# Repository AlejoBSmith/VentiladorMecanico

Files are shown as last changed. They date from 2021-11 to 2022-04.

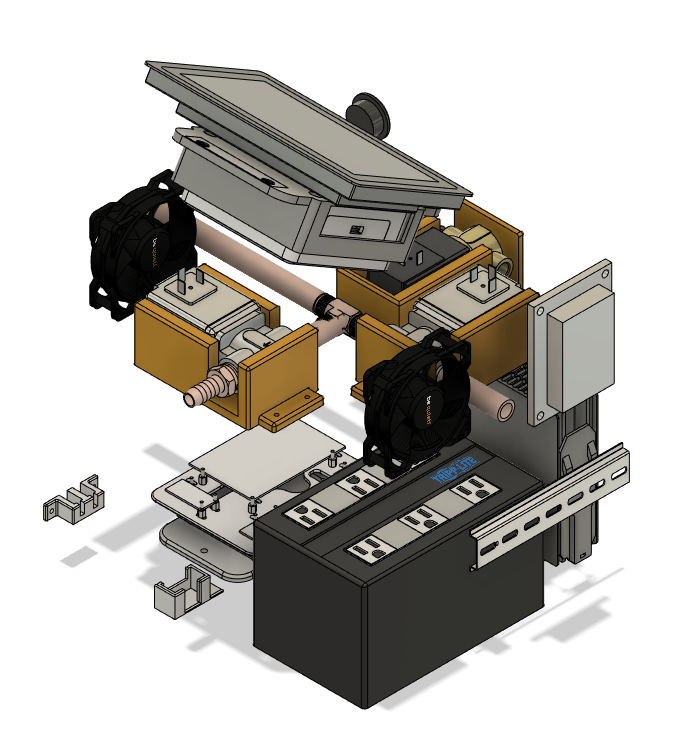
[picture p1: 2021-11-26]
Imágenes/17_materiales.PNG

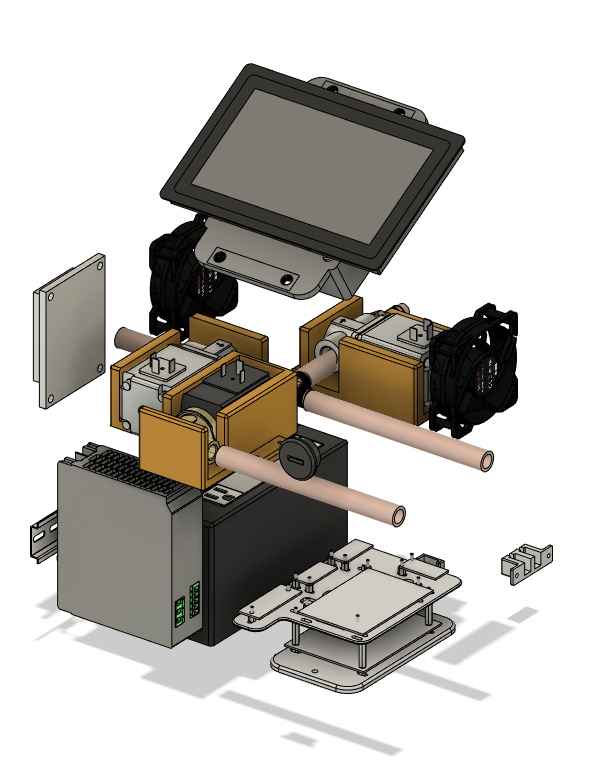
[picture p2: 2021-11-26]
Imágenes/16_materiales.PNG

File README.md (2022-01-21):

# VentiladorMecanico

If used for research purposes, please cite this work as:
A. Von Chong et al., "Low-cost, rapidly deployable emergency mechanical ventilators during the COVID-19 pandemic in a developing country: Comparing development feasibility between bag-valve and positive airway pressure designs," 2021 43rd Annual International Conference of the IEEE Engineering in Medicine & Biology Society (EMBC), 2021, pp. 7629-7635, doi: 10.1109/EMBC46164.2021.9630676.

This repository has been created to share the results of the mechanical ventilator developped in Panama, in response to the COVID-19 pandemic.

The mechanical ventilator is comprised by an electronic system, a pneumatic system, an embedded control algorithm, and a Human-Machine-Interface.

1. Electronic System
The circuit board files are held in folder "Circuito". There are 5 files:
PCB_Pressure_Sensor.json is the pcb for the pressure sensor MPX4006 and its conditioning circuit.
PCB_Main.json is the main circuit where the microcontroller is held and connection point between all sensors and actuators.
PCB_Flyback_diodes.json is an auxiliary circuit for adding the flyback diodes for th electrovalves.
PCB_Electrovalves_Sensors.json is the pcb containing the signals and power cables for the electrovalve's activation and the I2C sensors (flow and differential pressure)
PCB_Schematic is the complete system's electric schematic.

2. Pneumatic System

3. Embedded control algorithm
The system is controlled via a Teensy 4.1 microcontroller. It can be programmed with the Arduino IDE available at https://www.arduino.cc/en/software. The Teensy boards need and additional addon for the Arduino IDE, available at: https://www.pjrc.com/teensy/td_download.html.

Code is available at the "Arduino" folder. "Ventilator_main.ino" is the main code while "Variables.h" is the header file for variable declarations and initialization.

Additional libraries needed are:

4. Human-machine-interface (HMI)
A HMI is needed for data visualization and operating values change. Files for the external case are sized for a Raspberry Pi 10.1 Inch Touchscreen (available at: https://www.amazon.com/gp/product/B095R6SXX1/ref=asin_title?ie=UTF8&th=1). A Windows-based single-board computer (Seeed Studio Odyssey - X86J4125864) for interface hosting via a LabVIEW code available in the "LabVIEW" folder).

External case
The files for acrylic laser cutting of the ventilator's case is in the "Cortadora Láser" folder.

A descriptive video of the whole system is available at: https://youtu.be/rELKO5cxeyU (english) and https://youtu.be/uDOBed04stI (spanish)

Componentes utilizados
Cantidad
Electroválvula de acción directa Burkert        1
Electroválvula proporcional Burkert             2
Microcontroladora Teensy 4.1                    1
Sensor de flujo SFM3000                         1
Sensor diferencial de presión SDP811            1
Sensor de presión MPXV4006                      1
Convertidor analogico – digital ADS 1115        1
Convertidor de Nivel Lógico Bidireccional       1
Fuente DC NDR 120 24                            1
Regulador de Voltaje TrippLite                  1
Pantalla Táctil RPI Touch                       1
Filtro Antibacterial Armstrong                  1
Pulmón Inteligente IMT Analytics Rigel Medical  1
Adaptadores de cobre                            3
Tuberías de cobre                               3
Mosfet 15A 400W XY-MOS                          4
Extensores Micro-USB                            1
Extensores USB                                  2
Cable HDMI                                      1
Cable tipo-C                                    1
Odyssey Mini PC                                 1
Tornillos 6-32mm                                100
Tuercas 6-32mm                                  100
Separadores 30+6mm M.2                          15
Tuercas M.2                                     15
Tornillos 6mm M.2                               15
RielDIN                                         1
Soportes impresos en PLA 3D                     30
Acrílico 6mm espesor /cm2                       9000
Mezclador de Oxígeno                            1

Instructions and a video describing the assembly and operation of the mechanical ventilator will be added soon...

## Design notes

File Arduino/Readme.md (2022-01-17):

To be able to use this code, please download the Arduino dependencies (external libraries), links are provided below:

Sensirion arduino core library available at: https://github.com/Sensirion/arduino-core.git
Adafruit ADS1115 library: https://github.com/adafruit/Adafruit_ADS1X15.git
Adafruit BusIO library: https://github.com/adafruit/Adafruit_BusIO.git
Average.h: https://github.com/kbowerma/arduino/blob/3325685f809cfc3f29808d4946f0ae92c6fa6054/libraries/Average/Average.h
Medianfilterlib2: https://github.com/warhog/Arduino-MedianFilter.git
WTimer: https://github.com/W-walter70/WTimer-1.0-for-Arduino
StringSplitter: https://github.com/aharshac/StringSplitter.git

Modifications:
StringSplitter.h must be changed in line 14 to (at least) MAX=15

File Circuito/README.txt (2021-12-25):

Documents for Mechanical Ventilator's PCB crafting

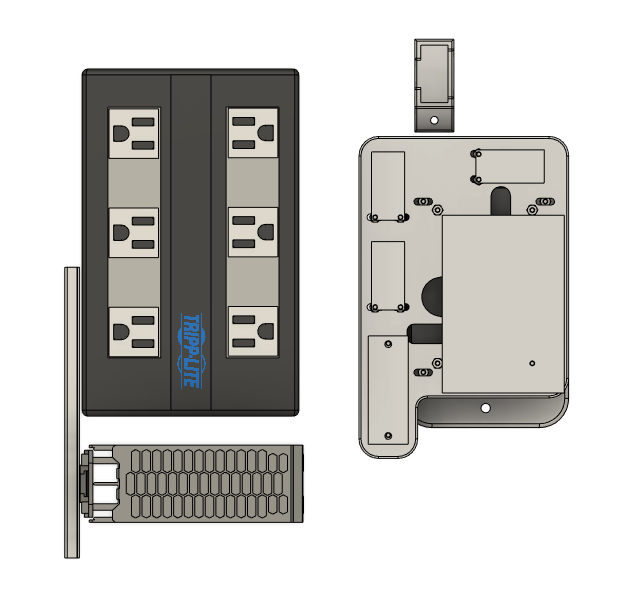
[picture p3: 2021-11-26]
Imágenes/19_electronica.PNG

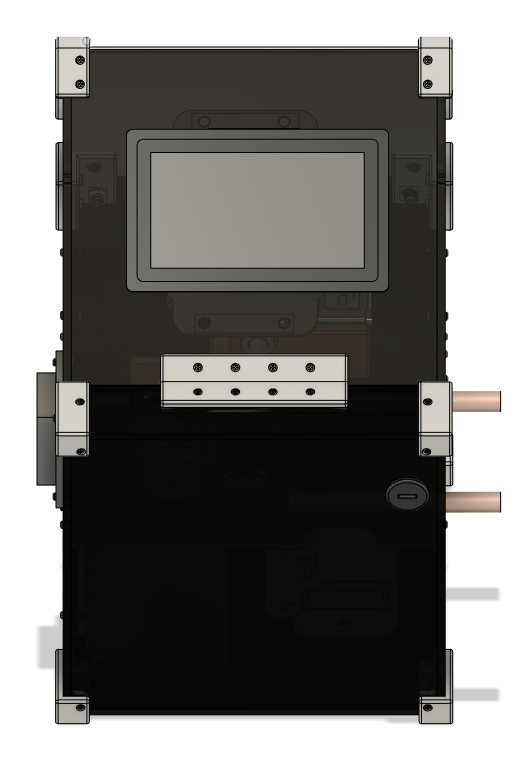
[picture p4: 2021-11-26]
Imágenes/3_isometrico.PNG

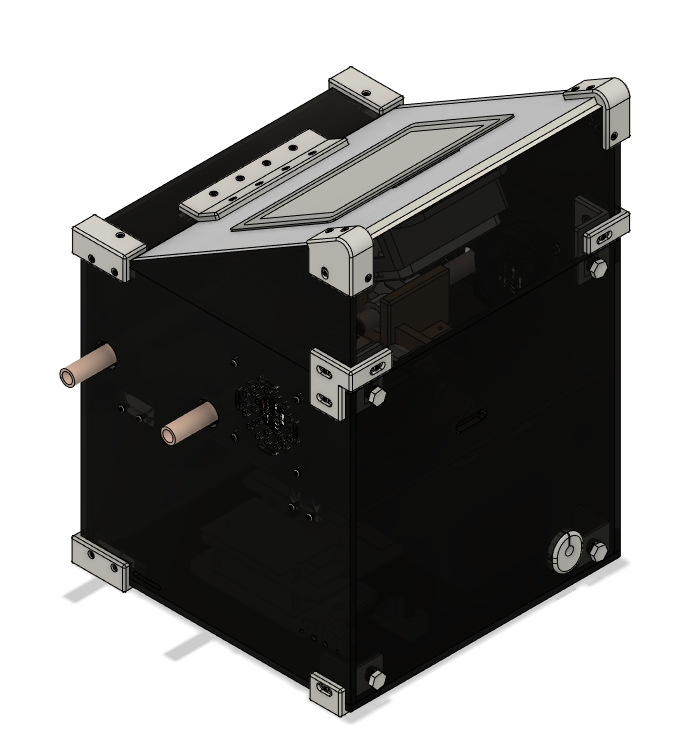
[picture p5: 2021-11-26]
Imágenes/6_isometrico.PNG

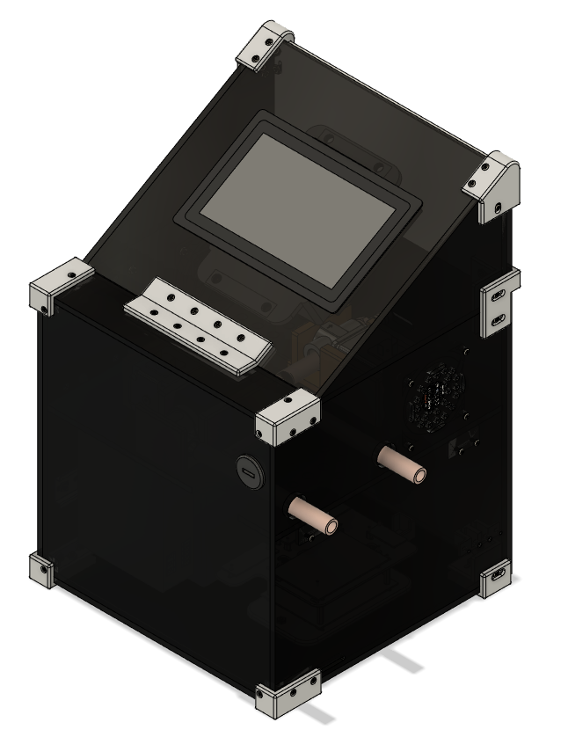
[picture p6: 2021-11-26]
Imágenes/2_isometrico.PNG

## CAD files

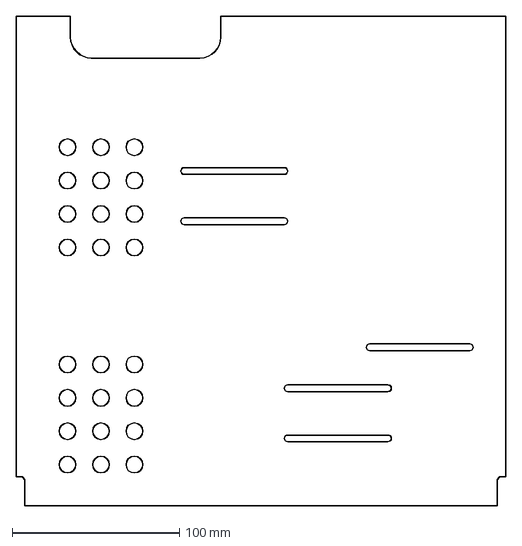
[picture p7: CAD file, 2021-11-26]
Cortadora Láser/Nivel1.dxf
293.0 x 293.0 mm

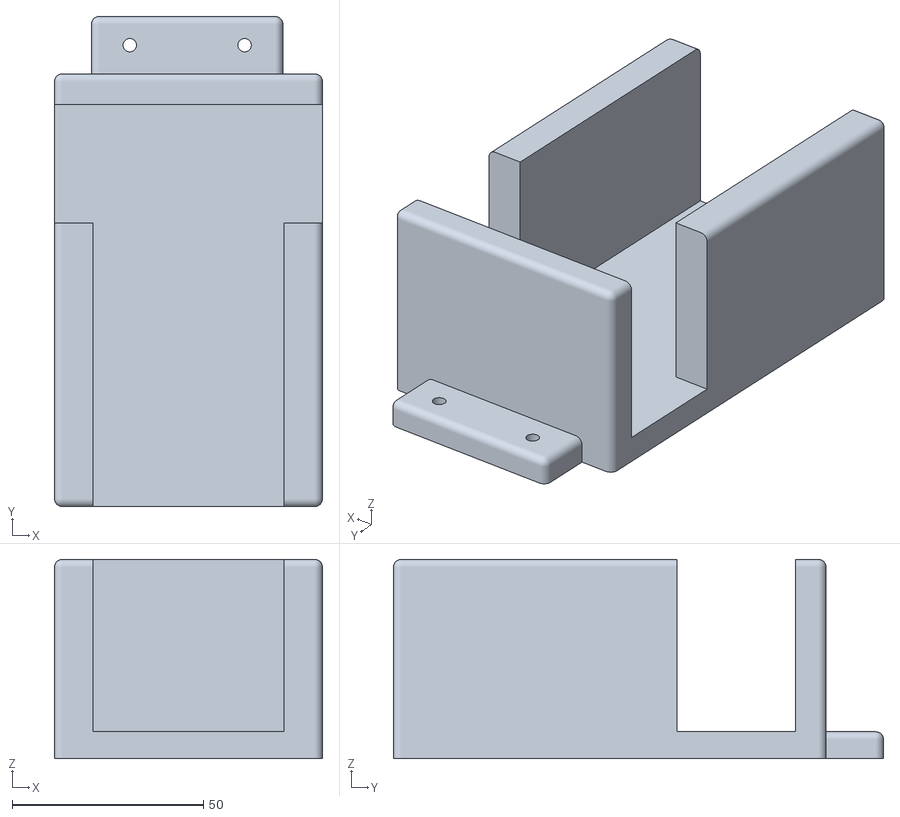
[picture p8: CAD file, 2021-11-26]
Impresión 3D/1_Electrovalvulas/Soporte2875.stl
70.0 x 128.0 x 52.0

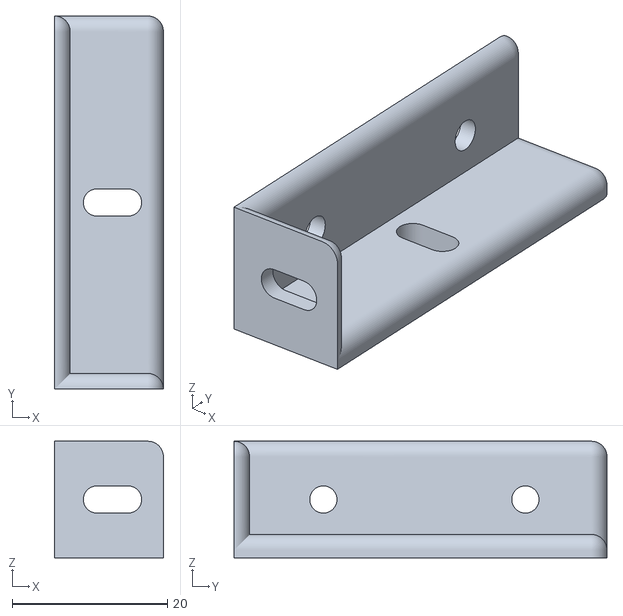
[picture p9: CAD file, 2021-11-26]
Impresión 3D/2_Inferiores/Izq_Inf_Int.stl
14.0 x 48.0 x 15.0

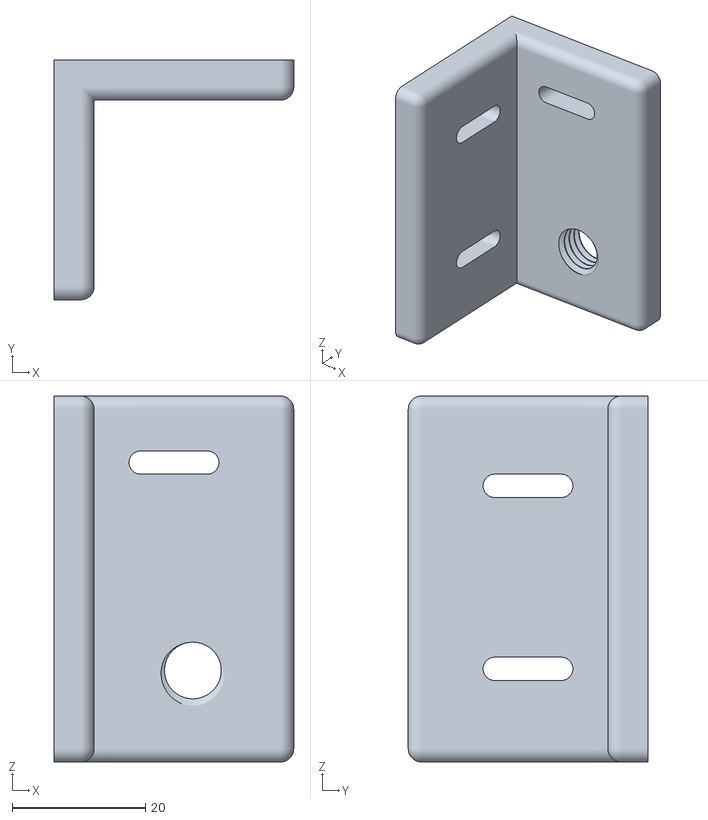
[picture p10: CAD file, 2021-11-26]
Impresión 3D/3_Superiores/Tra_Izq_Int_Sup_R.stl
36.0 x 36.0 x 55.0

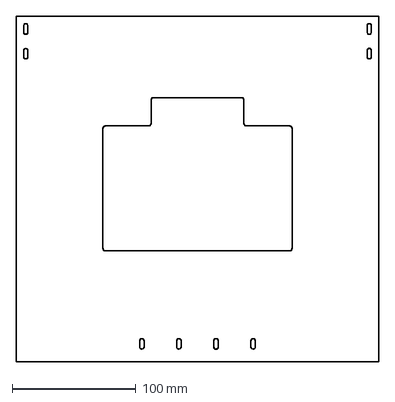
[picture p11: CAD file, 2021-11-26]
Cortadora Láser/paredFrontalInc.dxf
293.0 x 279.3 mm

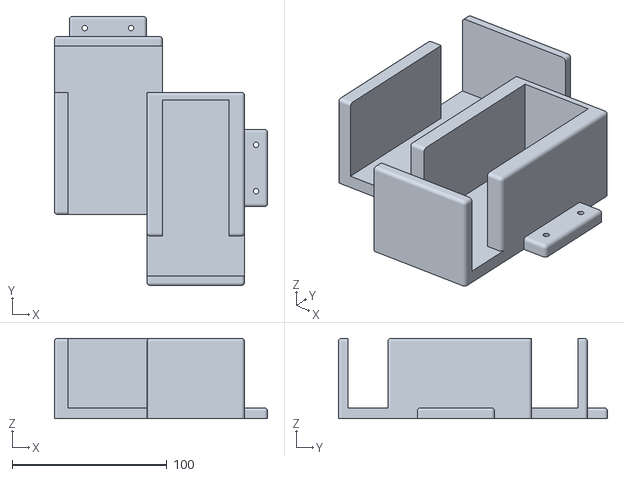
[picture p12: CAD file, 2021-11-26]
Impresión 3D/1_Electrovalvulas/Soporte2875-6027.stl
138.0 x 174.0 x 52.0

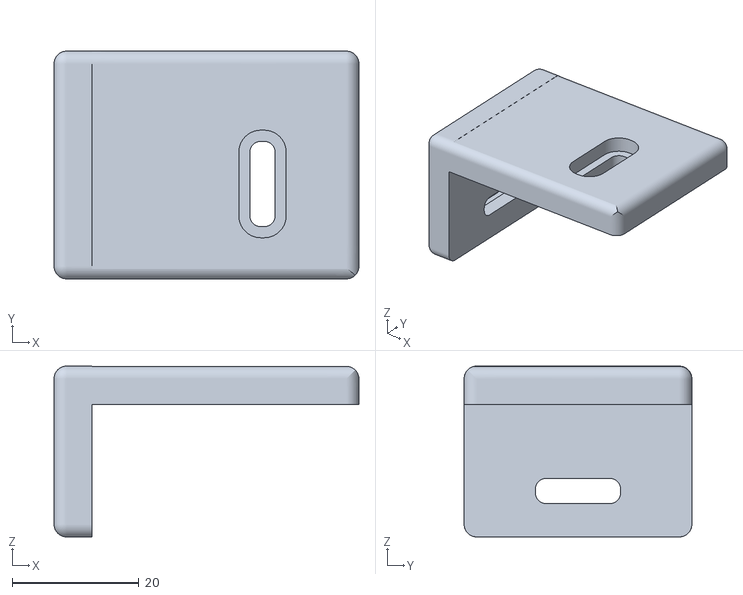
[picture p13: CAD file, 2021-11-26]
Impresión 3D/2_Inferiores/Tra_Der_Ext_Inf_R.stl
48.2 x 36.0 x 27.0

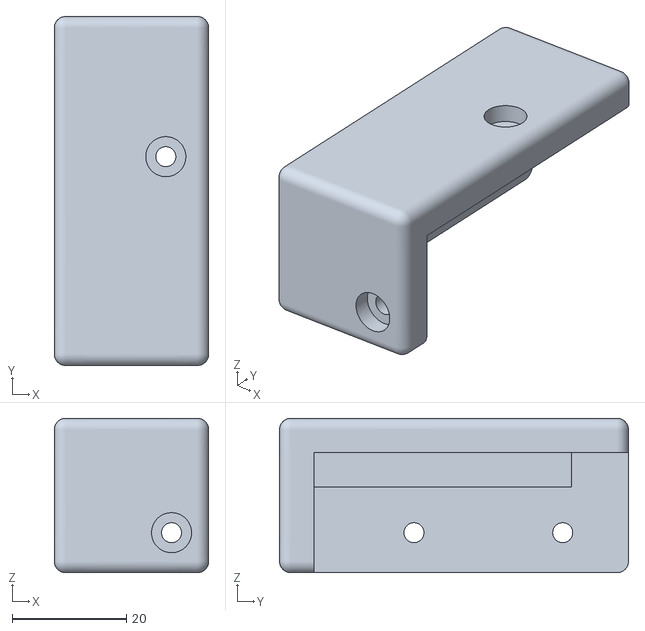
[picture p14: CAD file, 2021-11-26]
Impresión 3D/3_Superiores/Sup_Izq.stl
27.0 x 61.0 x 27.0

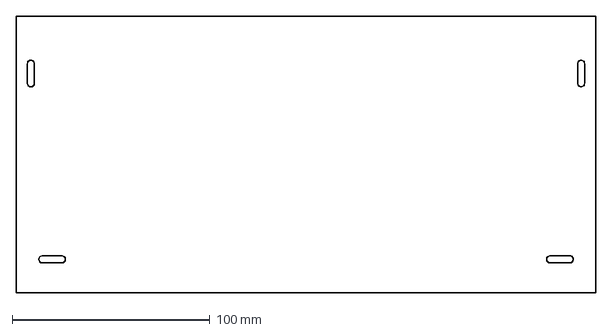
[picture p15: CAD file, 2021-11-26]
Cortadora Láser/paredTraseroSup.dxf
293.0 x 139.9 mm

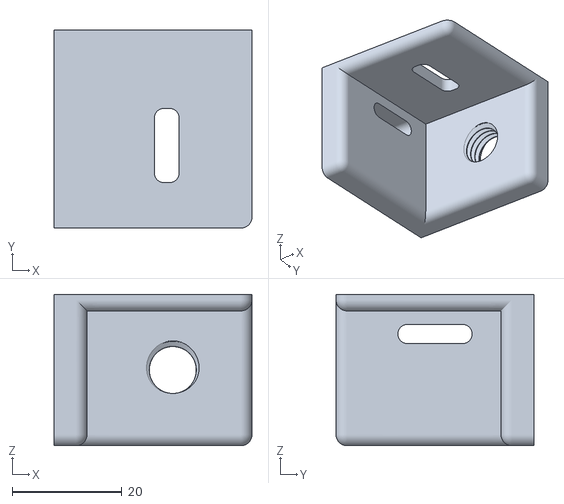
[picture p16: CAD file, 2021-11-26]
Impresión 3D/2_Inferiores/Tra_Der_Int_Inf_R.stl
36.0 x 36.0 x 27.5

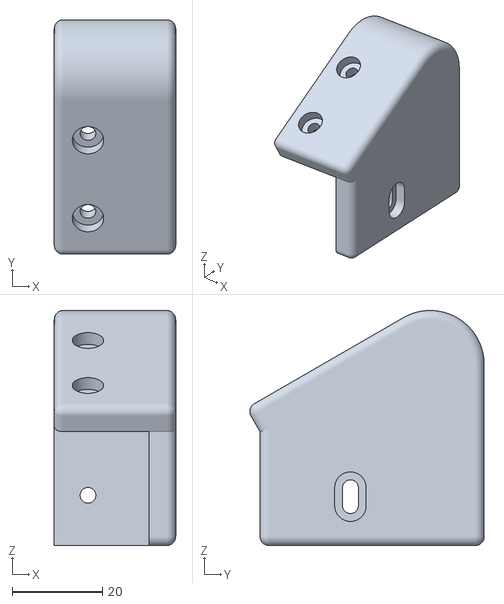
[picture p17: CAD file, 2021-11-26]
Impresión 3D/3_Superiores/Esq_Der_Sup.stl
27.0 x 52.1 x 52.2

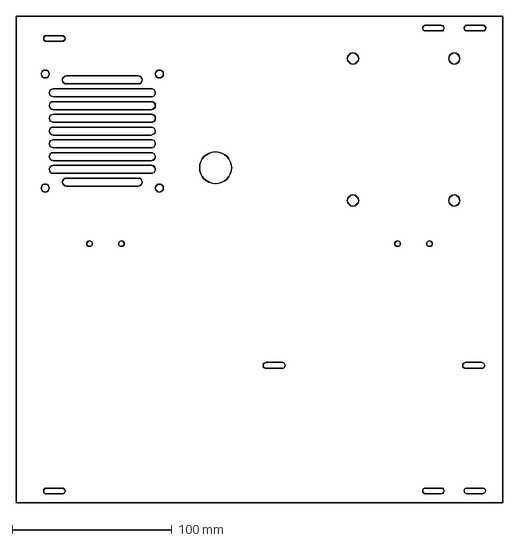
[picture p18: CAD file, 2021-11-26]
Cortadora Láser/paredIzquierdoInf.dxf
305.0 x 305.0 mm

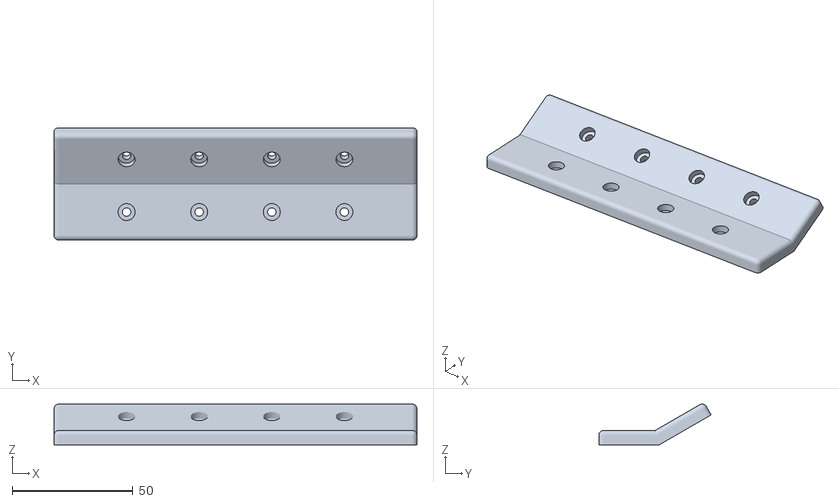
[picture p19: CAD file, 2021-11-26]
Impresión 3D/3_Superiores/Inclinado.stl
150.0 x 46.5 x 16.9

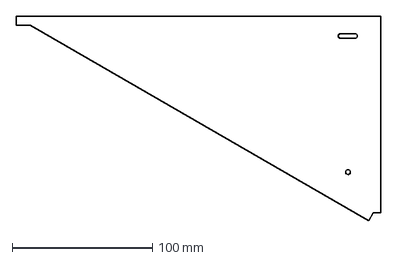
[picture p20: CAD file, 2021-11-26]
Cortadora Láser/paredIzquierdoSup.dxf
259.5 x 145.6 mm

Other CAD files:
Impresión 3D/2_Inferiores/Der_Inf_Ext.stl
Impresión 3D/2_Inferiores/Nivel1.stl
Impresión 3D/3_Superiores/Tra_Izq_Ext_Sup_R.stl
Cortadora Láser/paredFrontal.dxf
Cortadora Láser/Nivel0.dxf
Cortadora Láser/paredDerechoSup.dxf
Impresión 3D/2_Inferiores/Der_Inf_Int.stl
Impresión 3D/2_Inferiores/Izq_Inf_Ext.stl
Impresión 3D/2_Inferiores/Tra_Izq_Ext_Inf_R.stl
Impresión 3D/2_Inferiores/Tra_Izq_Int_Inf_R.stl
Impresión 3D/3_Superiores/Esq_Izq_Sup.stl
Impresión 3D/3_Superiores/Inclinado_Int.stl
Impresión 3D/3_Superiores/Sup_Der.stl
Impresión 3D/3_Superiores/Sup_Der_Int.stl
Impresión 3D/3_Superiores/Sup_Izq_Int.stl
Impresión 3D/3_Superiores/Tra_Der_Ext_Sup_R.stl
Impresión 3D/3_Superiores/Tra_Der_Inr_Sup_R.stl

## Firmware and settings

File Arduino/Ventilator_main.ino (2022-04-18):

// Corregir rutina de sdp811, actualmente dura 10 ms

#include <StringSplitter.h>
#include <WTimer.h>
#include <Wire.h>
#include <Adafruit_ADS1X15.h>
#include <MedianFilterLib2.h>
#include <movingAvg.h>
#include <Average.h>
#include <Separador.h>
#include "Variables.h"
#include <Arduino.h>
#include <SensirionI2CSdp.h>
#define sfm3300i2c 0x40

MedianFilter2<int> medianFilter2(3);
WTimer mytimers;
Adafruit_ADS1115 ads1115;
Separador HMI;
SensirionI2CSdp sdp;
elapsedMillis PlatTimer;
elapsedMillis ExhTimer;
elapsedMillis PCTimer;
elapsedMillis VCTimerInsp;

//Averaging functions:
movingAvg VIF_promedio(5);
movingAvg VEF_promedio(5);
movingAvg PIP_promedio(5);
movingAvg promediomovil(2);

void setup()
{
  //Set Teensys' IO pins and PWM frequency (PWM frequency is given in valve's datasheets)
  pinMode(Val_Ins,OUTPUT);
  pinMode(Val_Exh,OUTPUT);
  analogWriteFrequency(36,Frecuencia);
  analogWriteResolution(Resolucion);

  //Start averaging functions
  promediomovil.begin();
  VIF_promedio.begin();
  VEF_promedio.begin();
  PIP_promedio.begin();
 
  //--------------------------------------------------------------
  // Starts ADS1115 ADC
  ads1115.begin(0x48); //Address is 0x48 when ADDR pin is connected to GND
  ads1115.setDataRate(RATE_ADS1115_860SPS);
  // Starts communication with Sensirion SFM3300
  Wire.begin(); // Iniciar comunicación I2C
  while(!Serial) {} // let serial console settle
  Wire.beginTransmission(sfm3300i2c);
  Wire.write(0x10);
  Wire.write(0x00);
  Wire.endTransmission();
  //Starts communication with Sensirion SDP811
  sdp.begin(Wire, SDP8XX_I2C_ADDRESS_1);
  sdp.stopContinuousMeasurement();
  error_sdp = sdp.readProductIdentifier(productNumber, serialNumber, serialNumberSize);
  error_sdp = sdp.startContinuousMeasurementWithDiffPressureTCompAndAveraging();
  //--------------------------------------------------------------
}

void loop()
{
// First check if any of the operating values from the HMI have changed
  if (Serial.available() > 0)
  {
    StringEntrada = Serial.readStringUntil('\n');
    StringSplitter *splitter = new StringSplitter(StringEntrada, ',', 40);  // new StringSplitter(string_to_split, delimiter, limit)
    inicio = splitter->getItemAtIndex(0).toInt();
    Porcentaje_apertura_valvula = splitter->getItemAtIndex(1).toInt();
    presion_soporte = splitter->getItemAtIndex(2).toInt();
    Peep_deseado = splitter->getItemAtIndex(3).toInt();
    Volumen_deseado = splitter->getItemAtIndex(4).toInt();
    Tiempo_Expiracion_ms = splitter->getItemAtIndex(5).toInt();
    Tiempo_Plateau_ms = splitter->getItemAtIndex(6).toInt();
    inicio_modoAsistido=splitter->getItemAtIndex(7).toInt();
    Start_caract=splitter->getItemAtIndex(8).toInt();
    TipoCaract_Rampa=splitter->getItemAtIndex(9).toInt();
    TipoCaract_Escalon=splitter->getItemAtIndex(10).toInt();
    Tiempo_InspiracionPC_ms=splitter->getItemAtIndex(11).toInt();
    kp=splitter->getItemAtIndex(12).toInt();
    ki=splitter->getItemAtIndex(13).toInt();
    ModoOperacion=splitter->getItemAtIndex(14).toInt();
  }
 
  mytimers.runTimers(millis()); //Timing function

  //------------------------------------------------------------------------------
  // Read sensors
  LeerADS1115();
  LeerSFM3300();
  LeerSDP811();
  //------------------------------------------------------------------------------

  Calculos(); //Sensor data conversion
  Mostrar_Datos(); //Sends variables through serial port
  modoAsistido(Presion);
 
  //Cycle time
  tiempofinal_ciclo=tiempoinicial_ciclo;
  tiempoinicial_ciclo=millis();
  deltaT_ciclo=tiempoinicial_ciclo-tiempofinal_ciclo;

  if (deltaT_ciclo <= 50)
  {
  acc_ciclo=acc_ciclo+deltaT_ciclo;
  }
 
  switch (estado)
  {
    //-------------------------------------------------------
    case 0: // Idle
      caso = 0;
      CierreValvulaInspiracion(); //Keeps inspiratory valve closed
      AperturaValvulaExhalacion(); //Keeps expiratory valve open
      volumen_inspiracion = 0;
      EtapaResp = 0;
      acc_ciclo = 0;
      VIF = 0;
      PIP = 0;
     
      if (inicio == 1 && Start_caract == 0 && Zero_calibration == 0) // Begins respiratory cycle and forces other operating modes to false
      {
        Start_caract = false;
        Zero_calibration = false;
        offsetFlow = sensor_flujo_bits;
        offsetPressure = ((0.002131)*sensor_presion_bits) -3.565;
        offsetDiffPress = sensor_diferencial_bits/37960.3;
        estado = 1;
      }
      if(Start_caract== 1 && inicio == 0 && Zero_calibration == 0) // Begins system characterization and forces other operating modes to false
      {
        n = valor_inicial_PWM;
        estado = 10;
      }
      if (Zero_calibration == 1 && inicio == 0 && Start_caract == 0) // Sets offset values for sensor readings
      {
        f = 1;
        estado = 11;  
      }      
    break;
  //-------------------------------------------------------        
    case 1:
      AuxEtapa = false;
      caso = 1;
      if (Caract_Pulmon == 1) //Varies PWM output only if lung characterization is chosen
      {
        if(AuxCaractPulmon >= valor_final_PWM)
        {
          AuxCaractPulmon = valor_inicial_PWM;
          inicio = 0;
        }
        else
        {
        AuxCaractPulmon = AuxCaractPulmon + 50;
        }
      }
      tiempo_ciclo_actual= millis();
      PCTimer = 0; //only for first breath
      VCTimerInsp = 0;
      estado = 2;
      volumen_inspiracion=0; //Reset inspiratory volume to avoid integral drift
    break;
  //-------------------------------------------------------
    case 2: //Inspiration begin    
      EtapaResp = 1;
      caso = 2;
      CierreValvulaExhalacion();
      volumen_inspiracion += Flujo*deltaT_ciclo/60;

      if (ModoOperacion == 1) // Volume control mode
      {
        if(Presion >= (Peep_deseado + presion_soporte)||(Volumen_deseado <=  volumen_inspiracion)||(VCTimerInsp>Tiempo_max_insp_VC))
        {            
          // Closes inspiration valve if pressure or volume are exceeded
          CierreValvulaInspiracion();
          PIP = Presion;
          PlatTimer = 0;
          estado = 3; //State change
        }
        else // Opens inspiratory valve if neither set pressure or volume have been reached
        {
          EstadoValvulaInspiracion = true;
          if(Caract_Pulmon == 1) //For lung characterization, variable pwm
          {
            analogWrite(Val_Ins,AuxCaractPulmon);
          }
          else
          {
            AperturaValvulaInspiracion();
          }
        }
      }
      if (ModoOperacion == 0) //Pressure control mode
      {
        if ((PCTimer >= Tiempo_InspiracionPC_ms)||(Volumen_deseado <=  volumen_inspiracion))
        {
          // Maintains desired pressure until preset time is reached or volume is exceeded
          CierreValvulaInspiracion();
          PIP = Presion;
          errorIntegral = 0;
          PlatTimer = 0;
          estado = 3; //State change
        }
        else
        {
          EstadoValvulaInspiracion = true;
          AperturaValvulaInspiracion();
        }
      }
    break;
  //-------------------------------------------------------
    case 3: //Plateau (hold) time
      caso = 3;
      EtapaResp = 2;
      if (ModoOperacion == 1)
      {
        if ((PlatTimer >= Tiempo_Plateau_ms))
        {
          Pplat = Presion;
          ExhTimer = 0;
          Tiempo_Inspiracion = (millis()- tiempo_ciclo_actual)/1000; // Inspiration time including hold calc
          estado = 4;
          AperturaValvulaExhalacion();          
        }
      }
      else
      {
        Pplat = Presion;
        ExhTimer = 0;
        Tiempo_Inspiracion = (millis()- tiempo_ciclo_actual)/1000; // Inspiration time including hold calc
        estado = 4;
        AperturaValvulaExhalacion();
      }
    break;
  //-------------------------------------------------------
    case 4: //Exhalacion    
      caso = 4;
      if (ExhTimer >= Tiempo_Expiracion_ms)
      {
        Peep = Presion;
        if (inicio==1)
        {
          PCTimer = 0;
          VCTimerInsp = 0;
          estado = 2;
          volumen_inspiracion = 0;
          PwmOutAux = valor_inicial_PWM;
        }
        else
        {
          estado=0;
        }
        EtapaResp =3 ;  
        duracion_ciclo=acc_ciclo; //en ms  
        acc_ciclo=0; //reinicia el contador del tiempo para los BPM
      }
      else
      {
        if (inicio_modoAsistido ==1) //If assisted mode is on
        {
          if (ExhTimer >= (Tiempo_Expiracion_ms/3)) //Checks wether 33% of expiratory time has passed before checking pressure variability threshold
          {
            if (abs(derivada)>=10) //Pressure sensitivity (diff Pressure)
            {
              PCTimer = 0;
              estado = 1; //Starts a new inpiratory cycle
              duracion_ciclo=acc_ciclo;
              acc_ciclo=0;
              ExhTimer=0;
              break;
            }
          }
        }
        if(Presion <= Peep_deseado)   //PEEP setting
        {
          EtapaResp = 4;
          AuxEtapa = true;
          CierreValvulaExhalacion();      
        }
        else
        {
          if(AuxEtapa == false)
          EtapaResp = 5;          
        }
      }
    break;
  //-------------------------------------------------------
    case 10: //Valve characterization
    caso = 10;
    CaracterizarValvula(Tiempo_incremento_rampa,incremento_n_rampa);
    break;
  //-------------------------------------------------------
    default:
    //Nada de momento
    break;
  }
}

void LeerADS1115()
{
  sensor_presion_bits = ads1115.readADC_SingleEnded(1); // Sensor de Presión
}

void LeerSFM3300()
{
  if (2 == Wire.requestFrom(sfm3300i2c, 2))
  {
    uint16_t a = Wire.read();
    uint8_t  b = Wire.read();
    a = (a<<8) | b;
    sensor_flujo_bits = ((float)a - 32000) / 140;
    if(abs(sensor_flujo_bits)>=100)
    {
      Wire.begin(); // Iniciar comunicación I2C
      while(!Serial) {} // let serial console settle
      Wire.beginTransmission(sfm3300i2c);
      Wire.write(0x10);
      Wire.write(0x00);
      Wire.endTransmission();
    }
  }
}

void LeerSDP811()
{
  error_sdp = sdp.readMeasurement(differentialPressure, temperature);
}

void CaracterizarValvula(int Tiempo_incremento_rampa,int incremento_n_rampa)
{
  tiempofinal_caract=tiempoinicial_caract;
  tiempoinicial_caract=millis();
  deltaT_caract=tiempoinicial_caract-tiempofinal_caract;
  if (deltaT_caract <= 50)
  {
    acc_caract=acc_caract+deltaT_caract;
  }
  if (TipoCaract_Rampa == 0 && Start_caract == 1 && TipoCaract_Escalon == 0)
  {
    acc_caract=0; //Tiempo transcurrido inicializado
    subirPwm = 1;
    n=Pwm_Min;
    analogWrite(Val_Ins,n);
    digitalWrite(Val_Exh,LOW);
  }
  if(TipoCaract_Rampa == 0 && Start_caract == 0 && TipoCaract_Escalon == 0)
  {
    estado=0;
    acc_caract=0;
  }
  if(TipoCaract_Rampa == 1 && Start_caract == 1 && TipoCaract_Escalon == 0)
  {
    if((n<=Pwm_Max) && subirPwm == 1)
    {
      analogWrite(Val_Ins,n);
      digitalWrite(Val_Exh,LOW);
      mytimers.presetTimer(1,(Tiempo_incremento_rampa),TON); // Se coloca un PT de 100ms
      mytimers.timer[1].Start = true; // Iniciamos el timer
      if(mytimers.timer[1].Done) // Si el timer termina, entonces...
      {
        mytimers.timer[1].Start = false;
        n = n + incremento_n_rampa;
        if(n>= Pwm_Max)
        {
          bajarPwm = 1;
          subirPwm = 0;
        }
      }
    }
    else if((n>=Pwm_Min) && bajarPwm == 1)
    {
      analogWrite(Val_Ins,n);
      digitalWrite(Val_Exh,LOW);
      mytimers.presetTimer(1,(Tiempo_incremento_rampa),TON); // Se coloca un PT de 100ms
      mytimers.timer[1].Start = true; // Iniciamos el timer
      if(mytimers.timer[1].Done) // Si el timer termina, entonces...
      {
        mytimers.timer[1].Start = false;
        n = n - incremento_n_rampa;
        if(n <= Pwm_Min )
        {
          bajarPwm = 0;
          subirPwm = 1;
        }
      }
    }
  }

if(TipoCaract_Escalon == 1 && Start_caract == 1 && TipoCaract_Rampa==0)
  {
    if((n<=Pwm_Max) && subirPwm == 1)
    {
      analogWrite(Val_Ins,Pwm_Max);
      mytimers.presetTimer(1,(250),TON); // Se coloca un PT de 100ms
      mytimers.timer[1].Start = true; // Iniciamos el timer
      if(mytimers.timer[1].Done) // Si el timer termina, entonces...
      {
        mytimers.timer[1].Start = false;
        n = Pwm_Max;
        if(n>= Pwm_Max)
        {
          bajarPwm = 1;
          subirPwm = 0;
        }
      }
    }
    else if((n>=Pwm_Min) && bajarPwm == 1)
    {
      analogWrite(Val_Ins,Pwm_Min);
      digitalWrite(Val_Exh,HIGH);
      mytimers.presetTimer(1,(7000),TON); // Se coloca un PT de 100ms
      mytimers.timer[1].Start = true; // Iniciamos el timer
      if(mytimers.timer[1].Done) // Si el timer termina, entonces...
      {
        mytimers.timer[1].Start = false;
        n = Pwm_Min;
        if(n <= Pwm_Min )
        {
          bajarPwm = 0;
          subirPwm = 1;
        }
      }
    }
  }
}

void modoAsistido(float presion_entrada)
{
  mediana=medianFilter2.AddValue(presion_entrada);
  promedioant = promedio;
  promedio = promediomovil.reading(mediana);
  derivada = (promedio-promedioant)/0.005;
}

void Calculos()
{
  // Respiratory variable calcs
  IE = Tiempo_Expiracion_ms/(Tiempo_Inspiracion+Tiempo_Plateau_ms); //en ms
  MV = (volumen_inspiracion*BPM_calculado)/1000;
  if(duracion_ciclo != 0)
  {
    BPM_calculado = 60000/duracion_ciclo;
  }
  // Variable calc
  Presion = ((0.002131)*sensor_presion_bits) -3.565-offsetPressure;
  Flujo = sensor_flujo_bits-offsetFlow; //Scale factor from sfm3000 datasheet
  DeltaP = sensor_diferencial_bits/37960.3-offsetDiffPress; //Scale factor from sdp811 datasheet
}

void CierreValvulaInspiracion()
{
  EstadoValvulaInspiracion = false;
  analogWrite(Val_Ins,Pwm_Min);
  analogWrite(Val_PC,Pwm_Min);
}

void CierreValvulaExhalacion()
{
  EstadoValvulaExhalacion = false;
  digitalWrite(Val_Exh,LOW); // Cierre de válvula de Exhalación
}

void AperturaValvulaExhalacion()
{
  EstadoValvulaExhalacion = true;
  digitalWrite(Val_Exh,HIGH); // Abre válvula de Exhalación
}

void AperturaValvulaInspiracion()
{
  if (ModoOperacion == 1)
  {
  EstadoValvulaInspiracion = true;
  PwmOut = ((valor_inicial_PWM+(valor_final_PWM-valor_inicial_PWM))*Porcentaje_apertura_valvula/100);
  PwmOut = constrain(PwmOut,Pwm_Min,Pwm_Max);
  analogWrite(Val_Ins,PwmOut); // Abre válvula de Inspiración
  }
  else
  {
    errorPC = presion_soporte+Peep_deseado-Presion;
    errorIntegral += errorPC*(deltaT_ciclo/100);
    PwmOut = (kp*errorPC+ki*errorIntegral)+valor_inicial_PWM;
    PwmOut = constrain(PwmOut,valor_inicial_PWM,valor_final_PWM);
    PwmOutPC = 9400;
    PwmOutPC = constrain(PwmOutPC,valor_inicial_PWM,valor_final_PWM);
    analogWrite(Val_PC,PwmOutPC);
    analogWrite(Val_Ins,PwmOut); // Abre válvula de Inspiración
  }
}

void Mostrar_Datos()
{
  Serial.print("PresionM: ");
  Serial.print(Presion);
  Serial.print(",");
  Serial.print("PeepM: ");
  Serial.print(Peep);
  Serial.print(",");
  Serial.print("PresionD: ");
  Serial.print(presion_soporte);
  Serial.print(",");
  Serial.print("FlujoM: ");
  Serial.print(Flujo);
  Serial.print(",");
  Serial.print("VolumenM: ");
  Serial.print(volumen_inspiracion);
  Serial.print(",");
  Serial.print("PIPM: ");
  Serial.print(PIP);
  Serial.print(",");
  Serial.print("T_muestreoM: ");
  Serial.print(deltaT_ciclo);
  Serial.print(", ");
  Serial.print("PWMOut: ");
  Serial.print(PwmOutAux);
  Serial.print(", ");
  Serial.print("ErrorPC: ");
  Serial.print(errorPC);
  Serial.print(", ");
  Serial.print("Etapa_Res: ");
  Serial.print(EtapaResp);
  Serial.print(", ");
  Serial.print("duracion_ciclo: ");
  Serial.print(duracion_ciclo);
  Serial.print(", ");
  Serial.print("BPM: ");
  Serial.print(BPM_calculado);
  Serial.print(", ");
  Serial.print("PWM_Caract: ");
  Serial.print(n);
  Serial.print(", ");
  Serial.print("MV: ");
  Serial.print(MV);
  Serial.print(", ");
  Serial.print("DiffPressM: ");
  Serial.print(differentialPressure);
  Serial.print(", ");
  Serial.print("String: ");
  Serial.print(StringEntrada);
  Serial.println();
}

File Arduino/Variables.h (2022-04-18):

// Declaración de variables globales
float Flujo = 0; float Volumen = 0; float DeltaP = 0;
float Flujo_Avg = 0; float DeltaP_Avg = 0; float DeltaP_Final = 0;
float Presion = 0;
float DiferencialPresion=0;
float offsetFlow = 0;
float offsetPressure = 0;
float offsetDiffPress = 0;

//Parametros para ModoAsistido
int inicio_modoAsistido=0;
float mediana;
float promedioant;
float promedio;
float derivada=0;

//Parametros para calcular el tiempo de ciclo
float tiempofinal_ciclo, tiempoinicial_ciclo, deltaT_ciclo, acc_ciclo, duracion_ciclo;

//Parametros para calcular el tiempo de la caracterizacion
float tiempofinal_caract, tiempoinicial_caract, deltaT_caract, acc_caract, duracion_caract;

//Parametros para calcular VIF, VEF y PIP utilizando promediados.
float VIF_promedio_cal,VEF_promedio_cal,PIP_promedio_cal;

//Parametros para Sensirion SDP811
uint16_t error_sdp;
uint32_t productNumber;
uint8_t serialNumber[8];
uint8_t serialNumberSize = 8;
float differentialPressure;
float temperature;

// Parámetros PWM Teensy 4.1
int Frecuencia = 700; // En Hz
int Pwm_Min = 0; // Valor PWM mínimo permitido
int Pwm_Max = 16383; // Valor PWM máximo permitido
int Resolucion = 14; // bits
int Tiempo = 3000; // ms
int Val_Ins = 36; //Inspiratory valve
int Val_PC = 37; //Pressure control leak valve
int Val_Exh = 38; //Expiratory valve, on pin 38, Teensy 4.1 is NOT PWM capable

// Parametros para controlador P desde HMI
unsigned int Peep_deseado = 16;
int presion_soporte = 20;

//Variables en las cajas de texto el HMI
int estado = 0; //Estado inicial del sistema
int inicio = 0; //Boton On/Off en la HMI
int caso = 0;
int ModoOperacion = 1; //0 for pressure control, 1 for volume control
int PorcentajeValvula = 50;
int Tiempo_Inspiracion = 0;
unsigned int Tiempo_InspiracionPC_ms = 3000;
unsigned int Tiempo_max_insp_VC = 5000;
unsigned int Tiempo_Plateau_ms = 500;
unsigned int Tiempo_Expiracion_ms=3000;
int Volumen_deseado = 500;
int Presion_deseada = 25;

//Parametros de salida Pwm
int valor_final_PWM = 10000;
int valor_inicial_PWM = 5000;
float errorPC = 0;
float errorIntegral = 0;
unsigned int Porcentaje_apertura_valvula = 60;
int PwmOut = 0;
int PwmOutAux = valor_inicial_PWM;
int PwmOutPC = 0; // PWM value for leak valve during pressure control
int subirPwm = 1;
int bajarPwm = 0;

float aux,ultima ,lasttime=0,currenttime=0,currenttimeM=0,lasttimeM=0,tiempomuestra=0;
float integral = 0;
float dt = 0;

//Variables internas de operación
String bit_inicio;
String CaractValve;
String Modo;
String Ent_Valve;
String Ent_PEED_D;
String Ent_PS;
String Ent_Vesp;
String Ent_TP;
String Ent_Te;
String StringEntrada;

int TipoCaract_Rampa=0;
int TipoCaract_Escalon=0;
int n = Pwm_Min; //Incrementos de pwm para la caracterizacion
int Tiempo_incremento_rampa=1; //ms
int incremento_n_rampa=5;
int TipoCaract = 1;
int Start_caract = 0;
int f;
int AuxCaractPulmon = valor_inicial_PWM;
int datos_zero_cal = 300;

unsigned int EtapaResp;
unsigned int tiempoaccum;

bool Caract_Pulmon = 0;
bool AuxEtapa;
bool time_out;
bool EstadoValvulaInspiracion;
bool EstadoValvulaExhalacion;
bool SensorDetected;
bool FlowSens;
bool PressSens;
bool DiffSens;
bool Zero_calibration = 0;

float IE;
float tiempo_ciclo_actual = 0;
float tiempo_ciclo_anterior = 0;
float BPM_calculado;
float volumen_inspiracion;
float MV = 0;
float volumen_diferencial;
float presion_zero_cal = 0;
float flujo_zero_cal = 0;
float diferencial_zero_cal = 0;
float Pplat = 0;
float Peep = 0;
float PIP = 0;
float PEF = 0;
float VEF=10;
float VIF = 0;
float Tex = 3;
float sensor_presion_bits = 0;
float sensor_flujo_bits = 0;
float sensor_diferencial_bits = 0;
float datos_presion_zero_cal;
float datos_flujo_zero_cal;
float datos_diferencial_zero_cal;
float factor_sensor_presion = 21.24;
float factor_sensor_flujo = 77;
float factor_sensor_diferencial = 434;
float Mean;

// PID parameters
int kp = 10;
int ki = 5;
int kd = 0;
